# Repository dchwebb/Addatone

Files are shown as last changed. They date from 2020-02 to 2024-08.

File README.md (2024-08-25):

# Addatone
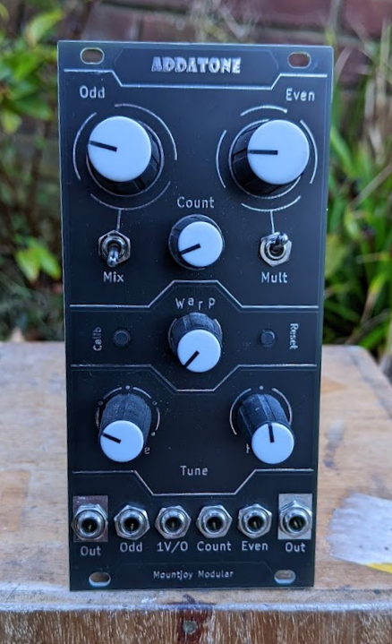
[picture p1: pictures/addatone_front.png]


Overview
--------

Addatone is a Eurorack oscillator using additive synthesis. It is a two channel oscillator with channel one outputting fundamental and odd harmonics and channel two fundamental and even harmonics.

Each channel has potentiometer and CV control over the number of harmonics with higher harmonics progressively attenuated. In addition a 'Count' pot and CV input hard-limit the total number of audible harmonics. A warp control progressively detunes the odd harmonics up and even harmonics down.

Channel one has a mix switch which allows a mix of both channels to be output from channel one. Channel two has a multiply switch which allows a multiple of both channels to be output from channel two (ie a ring modulation effect).

The final controls are an octave potentiometer covering a five octave range and a fine tune control covering around an octave.

Architecture
------------

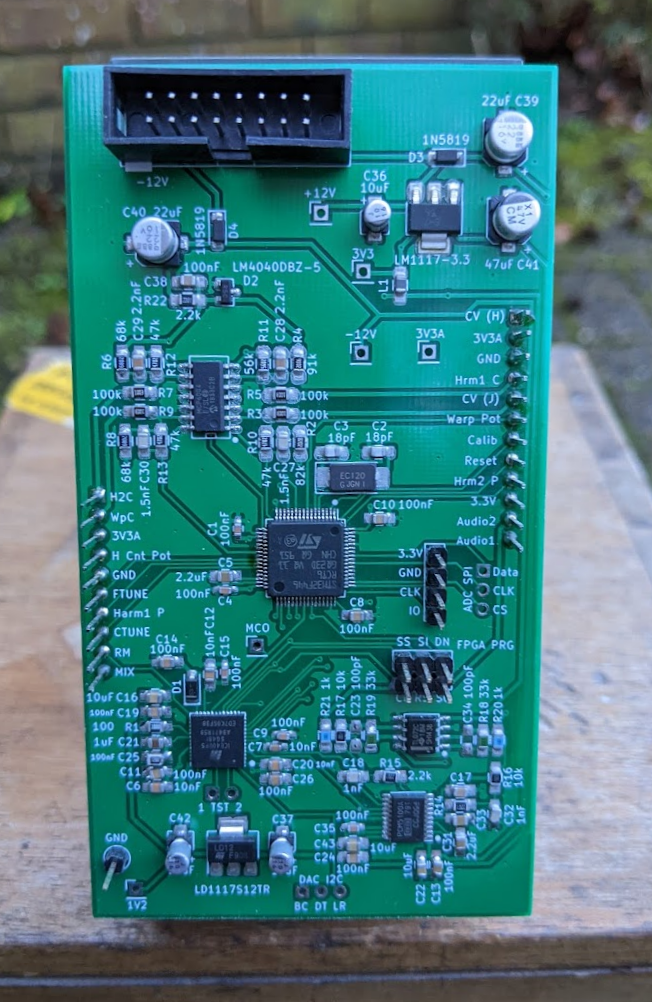
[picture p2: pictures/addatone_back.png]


The core sound generator is an ICE40UP5K FPGA from Lattice. This is responsible for generating the harmonics, mixing/multiplying and then outputting to the DAC via I2S protocol.

The module also contains an STM32F446 microcontroller which holds the FPGA bitstream in internal flash memory; this is used to program the FPGA on start-up via SPI. In addition the STM32 is used as an ADC to digitise and scale all potentiometer and CV control data. This is periodically transferred to the FPGA via SPI. The STM32 is clocked from an external 12MHz crystal. This is also used to drive the FPGA clock via the STM32 MCO (Master Clock Output) peripheral.

The DAC is a Texas Instruments PCM5100APW, operating 2 channels at 16 bits, 48kHz. Two op-amps are used to scale input CV voltages and to amplify the DAC output to Eurorack levels (8V peak to peak).

FPGA
----

A look-up table in block RAM (Sine_LUT) holds 2048 16 bit samples containing a single cycle sine wave. Individual harmonics are generated by traversing the LUT at a speed relative to the harmonic frequency.

The SamplePos_RAM 256 x 16 bit look-up table holds the current Sine LUT position of each harmonic. This position is advanced according to the harmonic's frequency at each sample and the sine sample is scaled and added to an accumulator. The initial values of the sample position LUT are pre-calculated to minimise 'crest factor'. If each harmonic started at position 0 of a sine wave then peaks and troughs would coincide to create a wave with an amplitude greater than the dynamic range of the system.

A graphical javascript tool to visualise and calculate minimal crest factor sample positions is available here:
https://htmlpreview.github.io/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

The FPGA receives its control data from the ADCs processed in the STM32. These are periodically sent via SPI and decoded using a custom peripheral (ADC_SPI_In).

The DAC_I2S module is a custom peripheral used to dispatch the final sample values to the DAC via the I2S protocol.

The 12MHz clock received from the STM32 MCO is scaled to the ICE40's maximum clock frequency of 48MHz.

The ICE40 bitstream is developed in Lattice's Radiant IDE. Full source code here: https://github.com/dchwebb/Addatone/tree/master/Addatone_ICE40

STM32 Microcontroller
---------------------

The module includes an STM32F446 MCU that carries out various helper roles. The firmware was developed in STM's CubeIDE and available here: https://github.com/dchwebb/Addatone/tree/master/Addatone_STM32F446

The FPGA bitstream is stored in the MCU's flash memory and is programmed into the FPGA at startup using an STM32 SPI peripheral (see fpgaHandler::ProgramBitstream method). Once the FPGA is programmed the ADC data derived from external CV control and potentiometers is processed, scaled and transmitted in a periodic packet to the FPGA via SPI (see fpgaHandler::SendControls method).

Calibration
-----------

The 'calib' button allows the setting of the mid point of the fine tune and the spread of the tuning. To start calibration turn the Octave and Fine Tune knobs to their mid point position.

Press the Calib button. Changing the Fine Tune knob will alter the pitch. Turning the Octave knob clockwise will decrease the tuning spread, and vice versa.

When calibration is complete press the Calib button again. Turning the Fine Tune knob to the center position should set the correct pitch.

To erase the configured calibration hold the Calib button down when powering on the module.

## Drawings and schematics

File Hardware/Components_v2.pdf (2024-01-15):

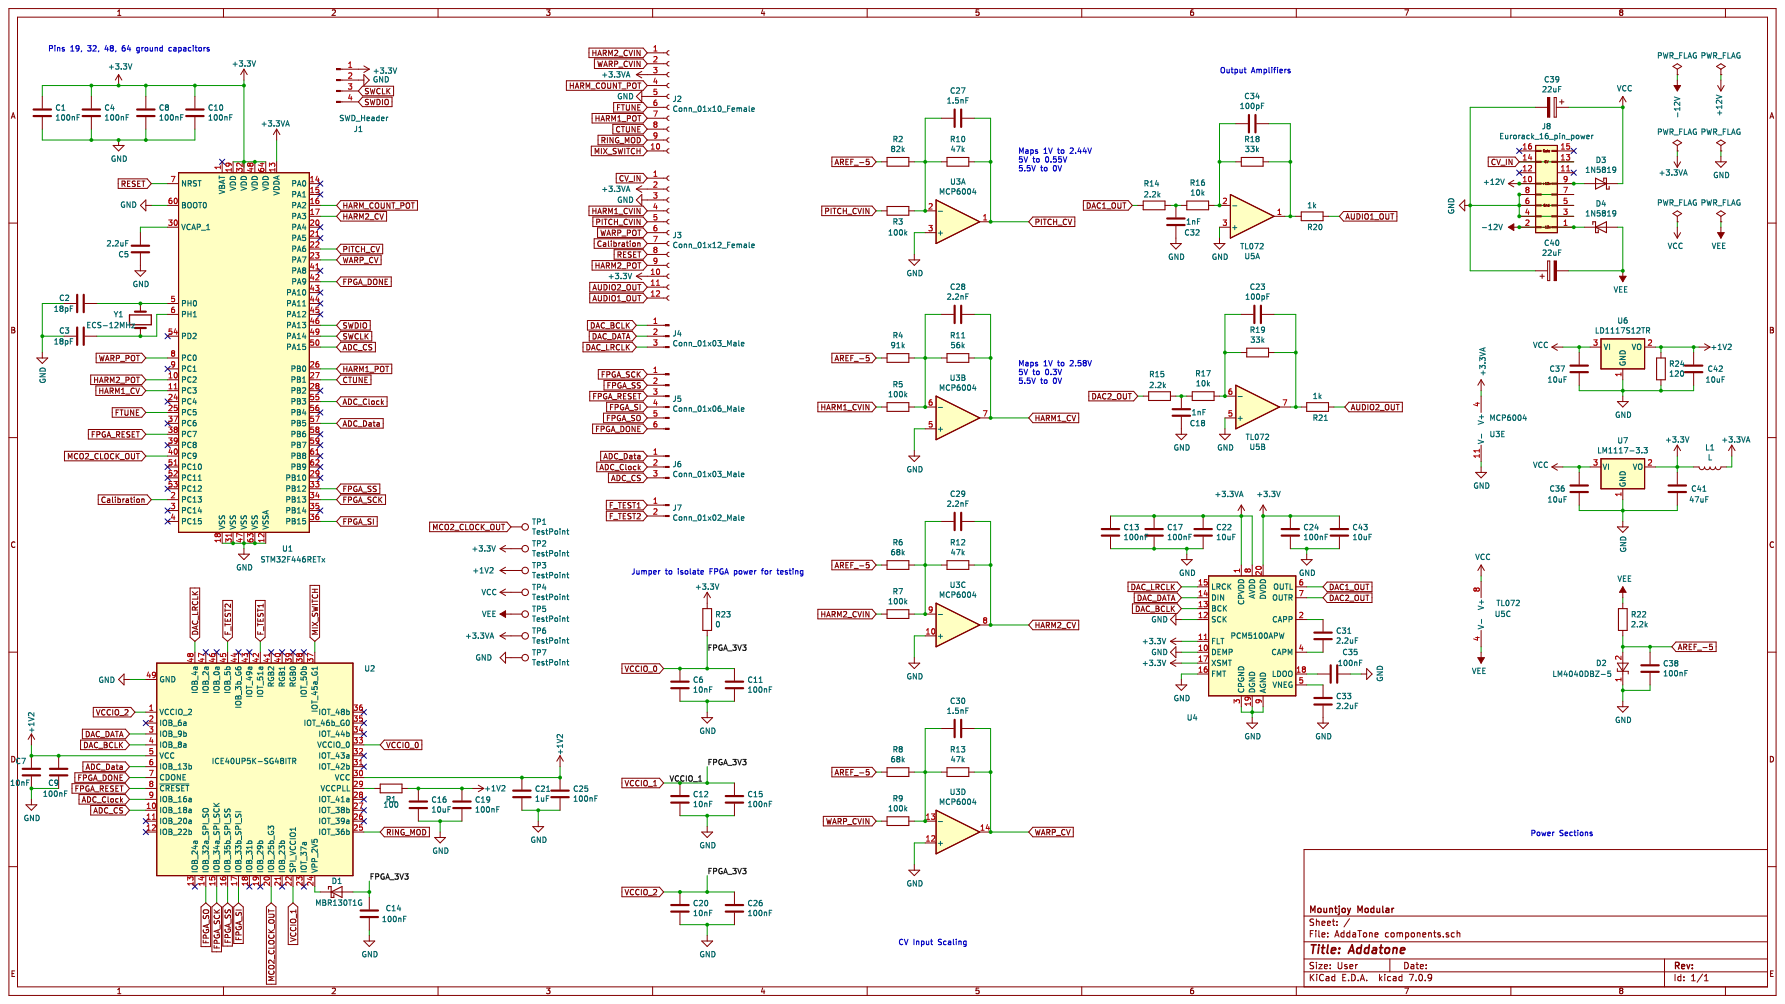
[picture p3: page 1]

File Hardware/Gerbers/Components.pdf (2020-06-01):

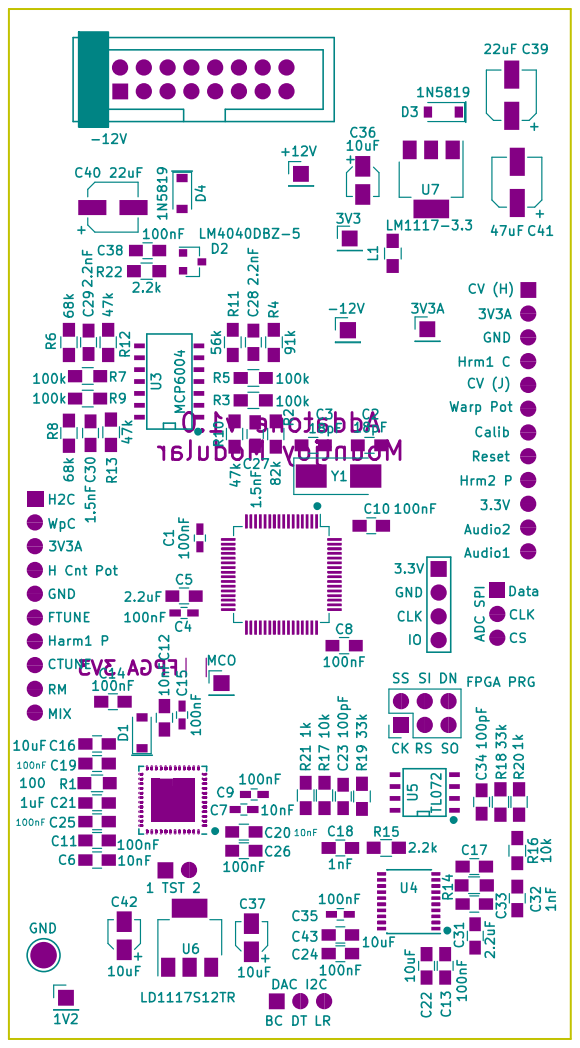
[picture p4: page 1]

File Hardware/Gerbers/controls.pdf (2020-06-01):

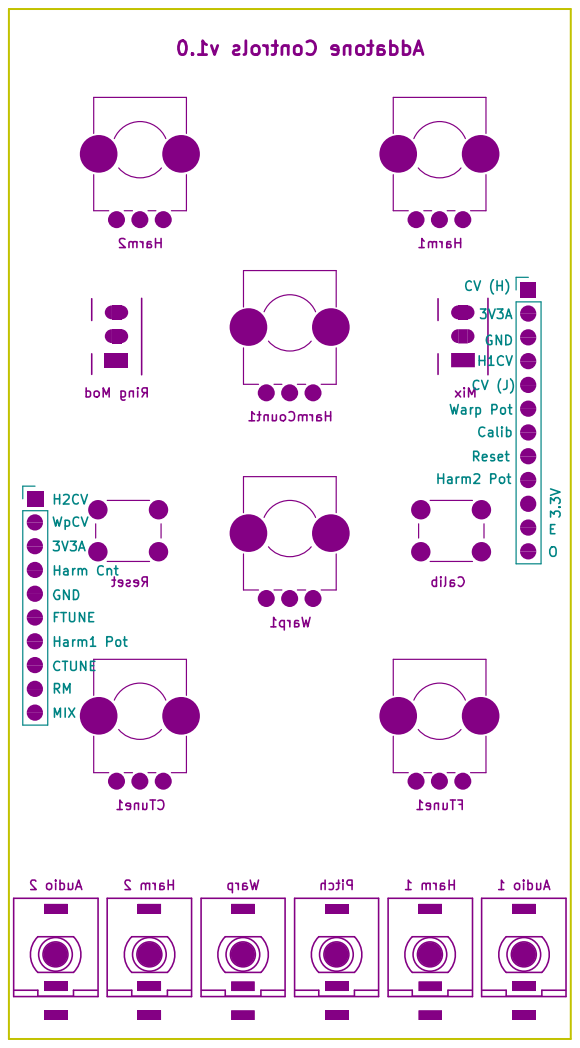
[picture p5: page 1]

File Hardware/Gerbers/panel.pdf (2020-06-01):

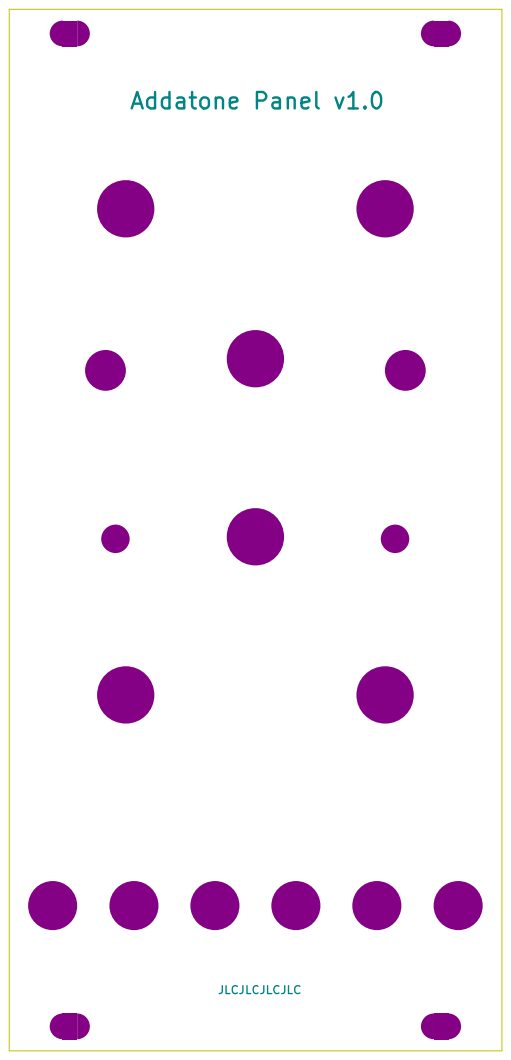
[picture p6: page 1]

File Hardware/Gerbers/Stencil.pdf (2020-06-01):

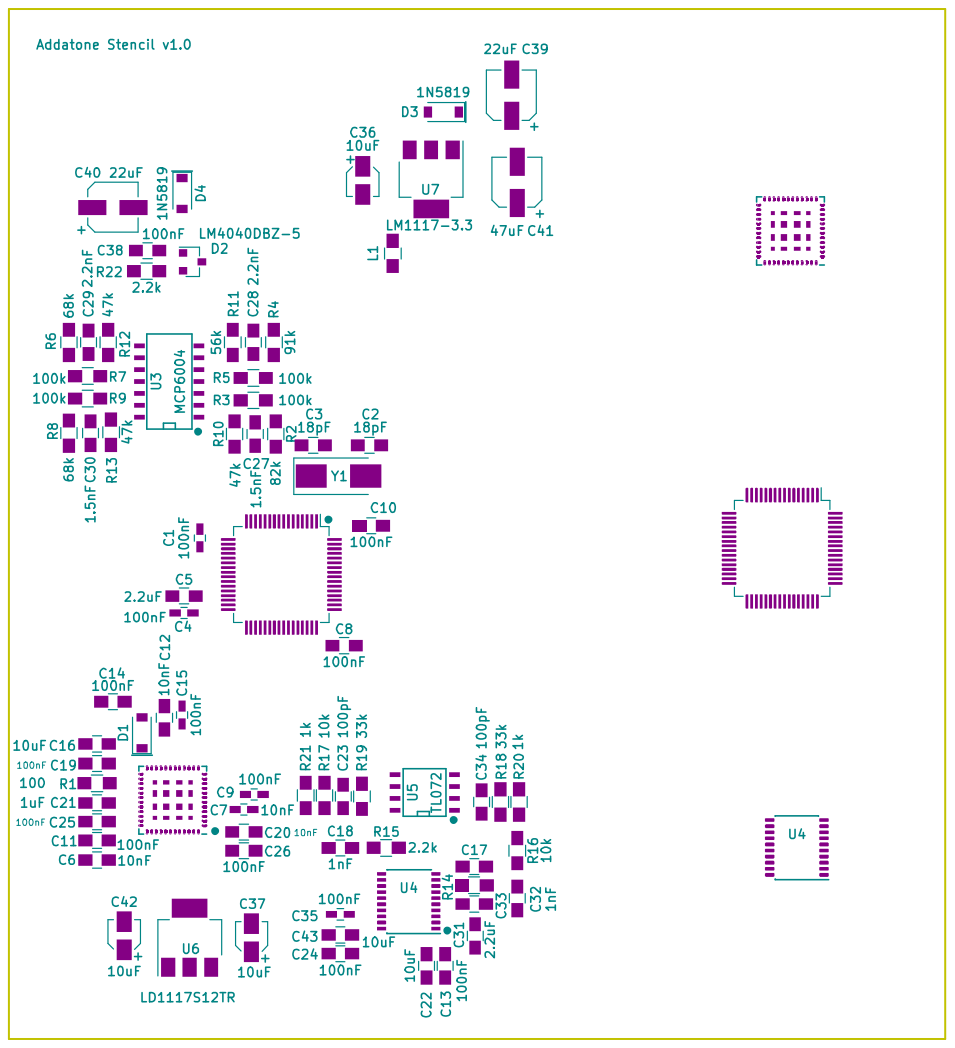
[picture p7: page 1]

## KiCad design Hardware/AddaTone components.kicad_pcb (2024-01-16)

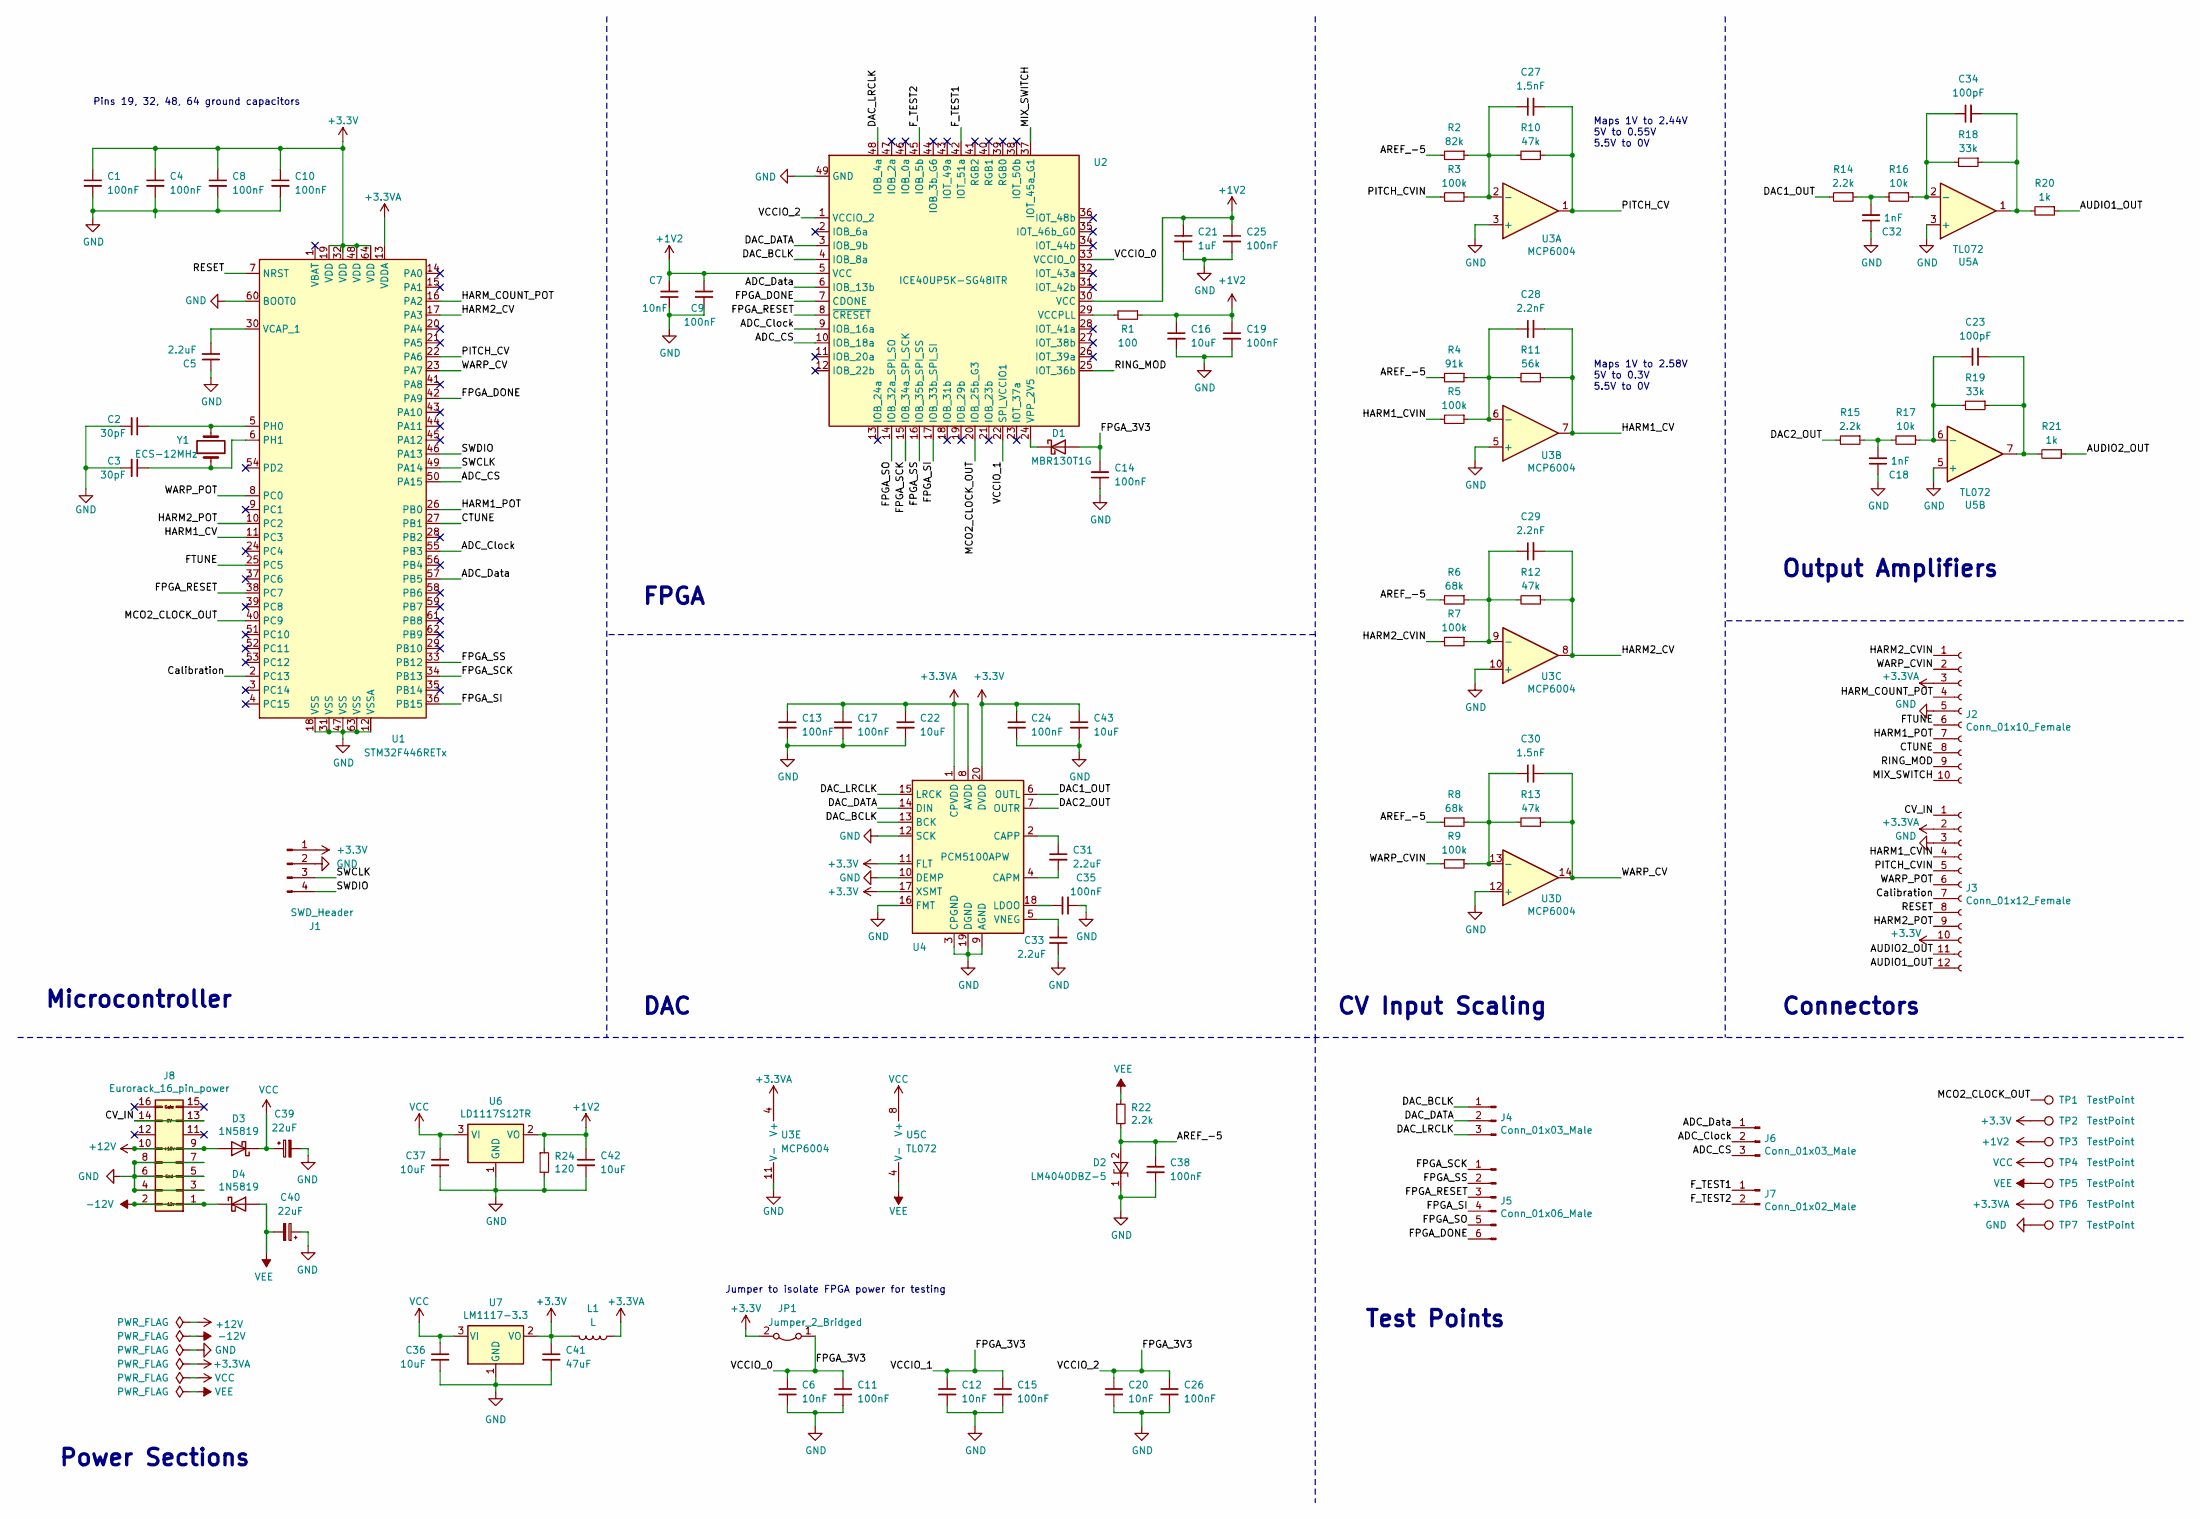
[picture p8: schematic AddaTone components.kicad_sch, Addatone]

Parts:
C1, C4, C9, C15, C35: 100nF; C_0603_1608Metric_Pad1.08x0.95mm_HandSolder
C2, C3: 30pF; C_0805_2012Metric_Pad1.18x1.45mm_HandSolder
C5, C31, C33: 2.2uF; C_0805_2012Metric_Pad1.18x1.45mm_HandSolder
C6, C7, C12, C20: 10nF; C_0805_2012Metric_Pad1.18x1.45mm_HandSolder
C8, C10, C11, C13, C14, C17, C19, C24, C25, C26, C38: 100nF; C_0805_2012Metric_Pad1.18x1.45mm_HandSolder
C16, C22, C43: 10uF; C_0805_2012Metric_Pad1.18x1.45mm_HandSolder
C18, C32: 1nF; C_0805_2012Metric_Pad1.18x1.45mm_HandSolder
C21: 1uF; C_0805_2012Metric_Pad1.18x1.45mm_HandSolder
C23, C34: 100pF; C_0805_2012Metric_Pad1.18x1.45mm_HandSolder
C27, C30: 1.5nF; C_0805_2012Metric_Pad1.18x1.45mm_HandSolder
C28, C29: 2.2nF; C_0805_2012Metric_Pad1.18x1.45mm_HandSolder
C36, C37, C42: 10uF; CP_Elec_3x5.3
C39, C40: 22uF; CP_Elec_5x5.3
C41: 47uF; CP_Elec_5x5.3
D1: MBR130T1G; D_SOD-123
D2: LM4040DBZ-5; SOT-23
D3, D4: 1N5819; D_SOD-123
J1: SWD_Header; SWD_header
J2: Conn_01x10_Female; PinSocket_1x10_P2.54mm_Vertical
J3: Conn_01x12_Female; PinSocket_1x12_P2.54mm_Vertical
J4, J6: Conn_01x03_Male; PinHeader_1x03_P2.54mm_Vertical
J5: Conn_01x06_Male; PinHeader_2x03_P2.54mm_Vertical
J7: Conn_01x02_Male; PinHeader_1x02_P2.54mm_Vertical
J8: Eurorack_16_pin_power; Eurorack_16_pin_header
JP1: Jumper_2_Bridged; SolderJumper-2_P1.3mm_Bridged_Pad1.0x1.5mm
L1: L; L_0805_2012Metric_Pad1.15x1.40mm_HandSolder
R1: 100; R_0805_2012Metric_Pad1.20x1.40mm_HandSolder
R2: 82k; R_0805_2012Metric_Pad1.20x1.40mm_HandSolder
R3, R5, R7, R9: 100k; R_0805_2012Metric_Pad1.20x1.40mm_HandSolder
R4: 91k; R_0805_2012Metric_Pad1.20x1.40mm_HandSolder
R6, R8: 68k; R_0805_2012Metric_Pad1.20x1.40mm_HandSolder
R10, R12, R13: 47k; R_0805_2012Metric_Pad1.20x1.40mm_HandSolder
R11: 56k; R_0805_2012Metric_Pad1.20x1.40mm_HandSolder
R14, R15, R22: 2.2k; R_0805_2012Metric_Pad1.20x1.40mm_HandSolder
R16, R17: 10k; R_0805_2012Metric_Pad1.20x1.40mm_HandSolder
R18, R19: 33k; R_0805_2012Metric_Pad1.20x1.40mm_HandSolder
R20, R21: 1k; R_0805_2012Metric_Pad1.20x1.40mm_HandSolder
R24: 120; R_0805_2012Metric_Pad1.20x1.40mm_HandSolder
TP1, TP2, TP3, TP4, TP5, TP6, TP7: TestPoint; TestPoint_THTPad_2.0x2.0mm_Drill1.0mm
U1: STM32F446RETx; LQFP-64_10x10mm_P0.5mm
U2: ICE40UP5K-SG48ITR; ICE40_QFN-48-1EP_7x7mm_Pitch0.5mm
U3: MCP6004; SOIC-14_3.9x8.7mm_P1.27mm
U4: PCM5100APW; SSOP-20_4.4x6.5mm_Pitch0.65mm_Round_Pads
U5: TL072; SOIC-8_3.9x4.9mm_P1.27mm
U6: LD1117S12TR; SOT-223
U7: LM1117-3.3; SOT-223
Y1: ECS-12MHz; Crystal_SMD_0603-2pin_6.0x3.5mm_HandSoldering

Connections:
+1V2: C7.1, C9.1, C16.1, C19.1, C21.1, C25.1, C42.1, R1.1, R24.1, TP3.1, U2.5 (VCC), U2.30 (VCC), U6.2 (VO)
+3.3VA: C13.1, C17.1, C22.1, J2.3, J3.2, L1.1, TP6.1, U1.13 (VDDA), U3.4 (V+), U4.1 (CPVDD), U4.8 (AVDD)
+3V3: C1.1, C4.1, C8.1, C10.1, C24.1, C41.1, C43.1, J1.1, J3.10, JP1.2 (B), L1.2, TP2.1, U1.19 (VDD), U1.32 (VDD), U1.48 (VDD), U1.64 (VDD), U4.11 (FLT), U4.17 (XSMT), U4.20 (DVDD), U7.2 (VO)
+12V: D3.2 (A), J8.9, J8.10
-12V: D4.1 (K), J8.1, J8.2
/ADC_CS: J6.3, U1.50 (PA15), U2.10 (IOB_18a)
/ADC_Clock: J6.2, U1.55 (PB3), U2.9 (IOB_16a)
/ADC_Data: J6.1, U1.57 (PB5), U2.6 (IOB_13b)
/AREF_-5: C38.1, D2.2 (A), R2.2, R4.2, R6.2, R8.2, R22.2
/AUDIO1_OUT: J3.12, R20.1
/AUDIO2_OUT: J3.11, R21.1
/CTUNE: J2.8, U1.27 (PB1)
/CV_IN: J3.1, J8.13, J8.14
/Calibration: J3.7, U1.2 (PC13)
/DAC1_OUT: R14.2, U4.6 (OUTL)
/DAC2_OUT: R15.2, U4.7 (OUTR)
/DAC_BCLK: J4.1, U2.4 (IOB_8a), U4.13 (BCK)
/DAC_DATA: J4.2, U2.3 (IOB_9b), U4.14 (DIN)
/DAC_LRCLK: J4.3, U2.48 (IOB_4a), U4.15 (LRCK)
/FPGA_3V3: C6.1, C11.1, C12.1, C14.2, C15.1, C20.1, C26.1, D1.2 (A), JP1.1 (A), U2.1 (VCCIO_2), U2.22 (SPI_VCCIO1), U2.33 (VCCIO_0)
/FPGA_DONE: J5.6, U1.42 (PA9), U2.7 (CDONE)
/FPGA_RESET: J5.3, U1.38 (PC7), U2.8 (~CRESET)
/FPGA_SCK: J5.1, U1.34 (PB13), U2.15 (IOB_34a_SPI_SCK)
/FPGA_SI: J5.4, U1.36 (PB15), U2.17 (IOB_33b_SPI_SI)
/FPGA_SO: J5.5, U2.14 (IOB_32a_SPI_SO)
/FPGA_SS: J5.2, U1.33 (PB12), U2.16 (IOB_35b_SPI_SS)
/FTUNE: J2.6, U1.25 (PC5)
/F_TEST1: J7.1, U2.42 (IOT_51a)
/F_TEST2: J7.2, U2.45 (IOB_5b)
/HARM1_CV: C28.2, R11.1, U1.11 (PC3), U3.7
/HARM1_CVIN: J3.4, R5.2
/HARM1_POT: J2.7, U1.26 (PB0)
/HARM2_CV: C29.2, R12.1, U1.17 (PA3), U3.8
/HARM2_CVIN: J2.1, R7.2
/HARM2_POT: J3.9, U1.10 (PC2)
/HARM_COUNT_POT: J2.4, U1.16 (PA2)
/MCO2_CLOCK_OUT: TP1.1, U1.40 (PC9), U2.20 (IOB_25b_G3)
/MIX_SWITCH: J2.10, U2.37 (IOT_45a_G1)
/PITCH_CV: C27.2, R10.1, U1.22 (PA6), U3.1
/PITCH_CVIN: J3.5, R3.2
/RESET: J3.8, U1.7 (NRST)
/RING_MOD: J2.9, U2.25 (IOT_36b)
/SWCLK: J1.3, U1.49 (PA14)
/SWDIO: J1.4, U1.46 (PA13)
/WARP_CV: C30.2, R13.1, U1.23 (PA7), U3.14
/WARP_CVIN: J2.2, R9.2
/WARP_POT: J3.6, U1.8 (PC0)
GND: C1.2, C2.2, C3.2, C4.2, C5.1, C6.2, C7.2, C8.2, C9.2, C10.2, C11.2, C12.2, C13.2, C14.1, C15.2, C16.2, C17.2, C18.1, C19.2, C20.2, C21.2, C22.2, C24.2, C25.2, C26.2, C32.1, C33.2, C35.1, C36.2, C37.2, C38.2, C39.2, C40.1, C41.2, C42.2, C43.2, D2.1 (K), J1.2, J2.5, J3.3, J8.3, J8.4, J8.5, J8.6, J8.7, J8.8, R24.2, TP7.1, U1.12 (VSSA), U1.18 (VSS), U1.31 (VSS), U1.47 (VSS), U1.60 (BOOT0), U1.63 (VSS), U2.49 (GND), U3.3 (+), U3.5 (+), U3.10 (+), U3.11 (V-), U3.12 (+), U4.3 (CPGND), U4.9 (AGND), U4.10 (DEMP), U4.12 (SCK), U4.16 (FMT), U4.19 (DGND), U5.3 (+), U5.5 (+), U6.1 (GND), U7.1 (GND)
unnamed: C18.2, R15.1, R17.2
unnamed: C23.2, R19.1, R21.2, U5.7
unnamed: C32.2, R14.1, R16.2
unnamed: C34.2, R18.1, R20.2, U5.1
unnamed: D1.1 (K), U2.24 (VPP_2V5)
unnamed: C2.1, U1.5 (PH0), Y1.2
unnamed: C3.1, U1.6 (PH1), Y1.1
unnamed: C5.2, U1.30 (VCAP_1)
unnamed: R1.2, U2.29 (VCCPLL)
unnamed: C27.1, R2.1, R3.1, R10.2, U3.2 (-)
unnamed: C28.1, R4.1, R5.1, R11.2, U3.6 (-)
unnamed: C29.1, R6.1, R7.1, R12.2, U3.9 (-)
unnamed: C30.1, R8.1, R9.1, R13.2, U3.13 (-)
unnamed: C31.2, U4.4 (CAPM)
unnamed: C31.1, U4.2 (CAPP)
unnamed: C35.2, U4.18 (LDOO)
unnamed: C33.1, U4.5 (VNEG)
unnamed: C34.1, R16.1, R18.2, U5.2 (-)
unnamed: C23.1, R17.1, R19.2, U5.6 (-)
VCC: C36.1, C37.1, C39.1, D3.1 (K), TP4.1, U5.8 (V+), U6.3 (VI), U7.3 (VI)
VEE: C40.2, D4.2 (A), R22.1, TP5.1, U5.4 (V-)

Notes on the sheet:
Pins 19, 32, 48, 64 ground capacitors
Test Points
Power Sections
DAC
Jumper to isolate FPGA power for testing
Output Amplifiers
Microcontroller
Maps 1V to 2.44V 5V to 0.55V 5.5V to 0V
Maps 1V to 2.58V 5V to 0.3V 5.5V to 0V
CV Input Scaling
Connectors
FPGA

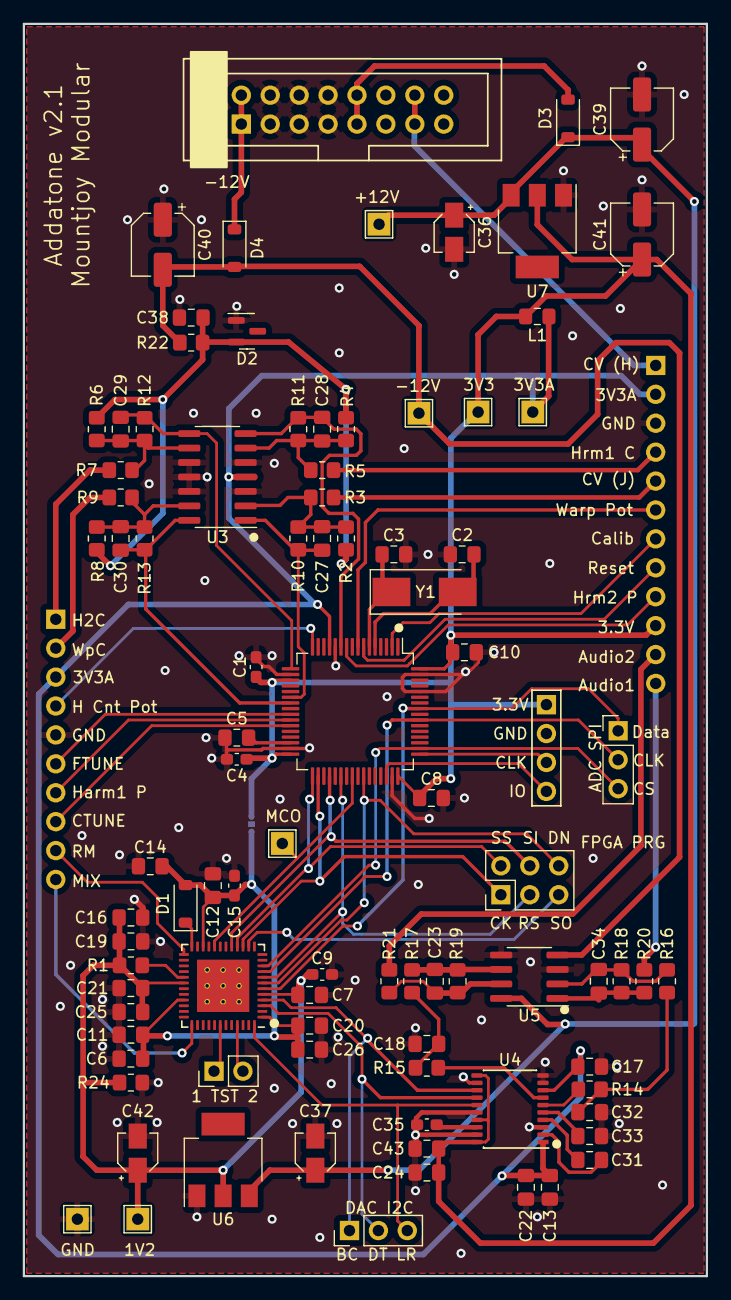
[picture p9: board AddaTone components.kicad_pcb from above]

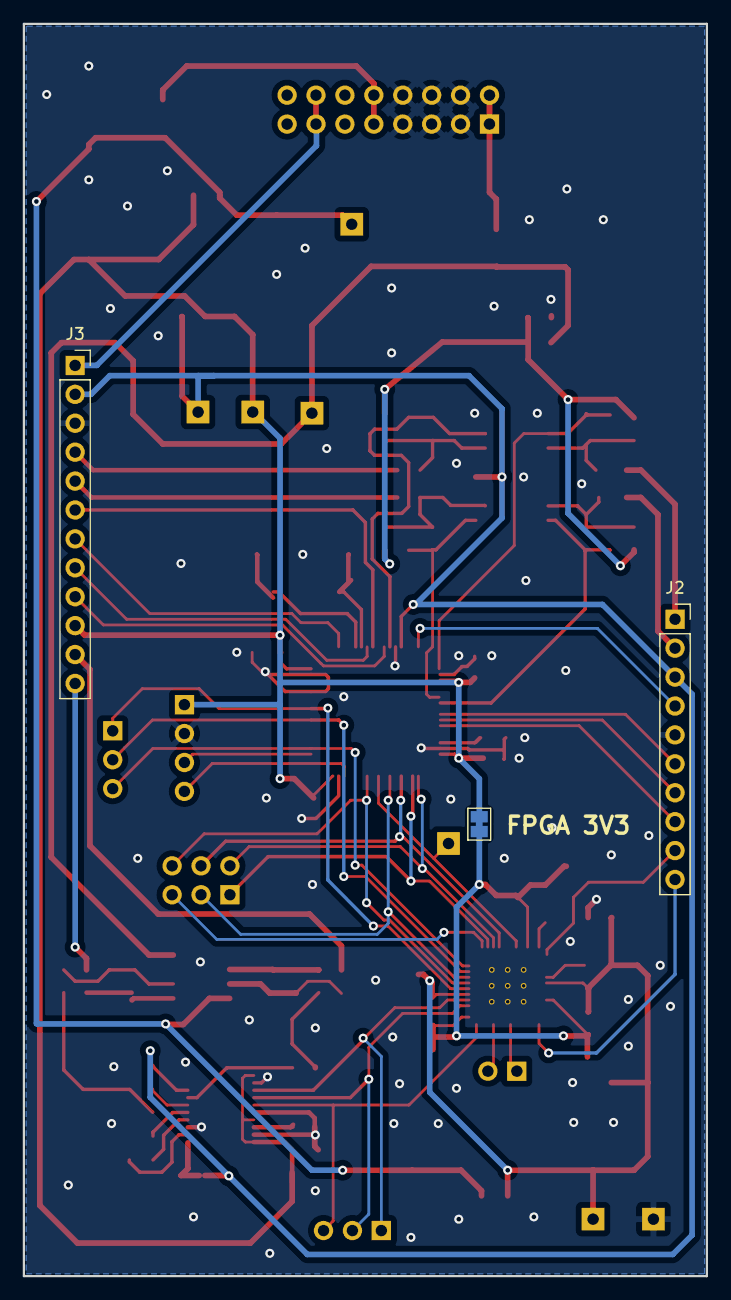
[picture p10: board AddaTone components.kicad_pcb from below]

Board: 2 copper layers, 60.0 x 110.0 mm, 95 parts (3 on the bottom side), 69 nets.

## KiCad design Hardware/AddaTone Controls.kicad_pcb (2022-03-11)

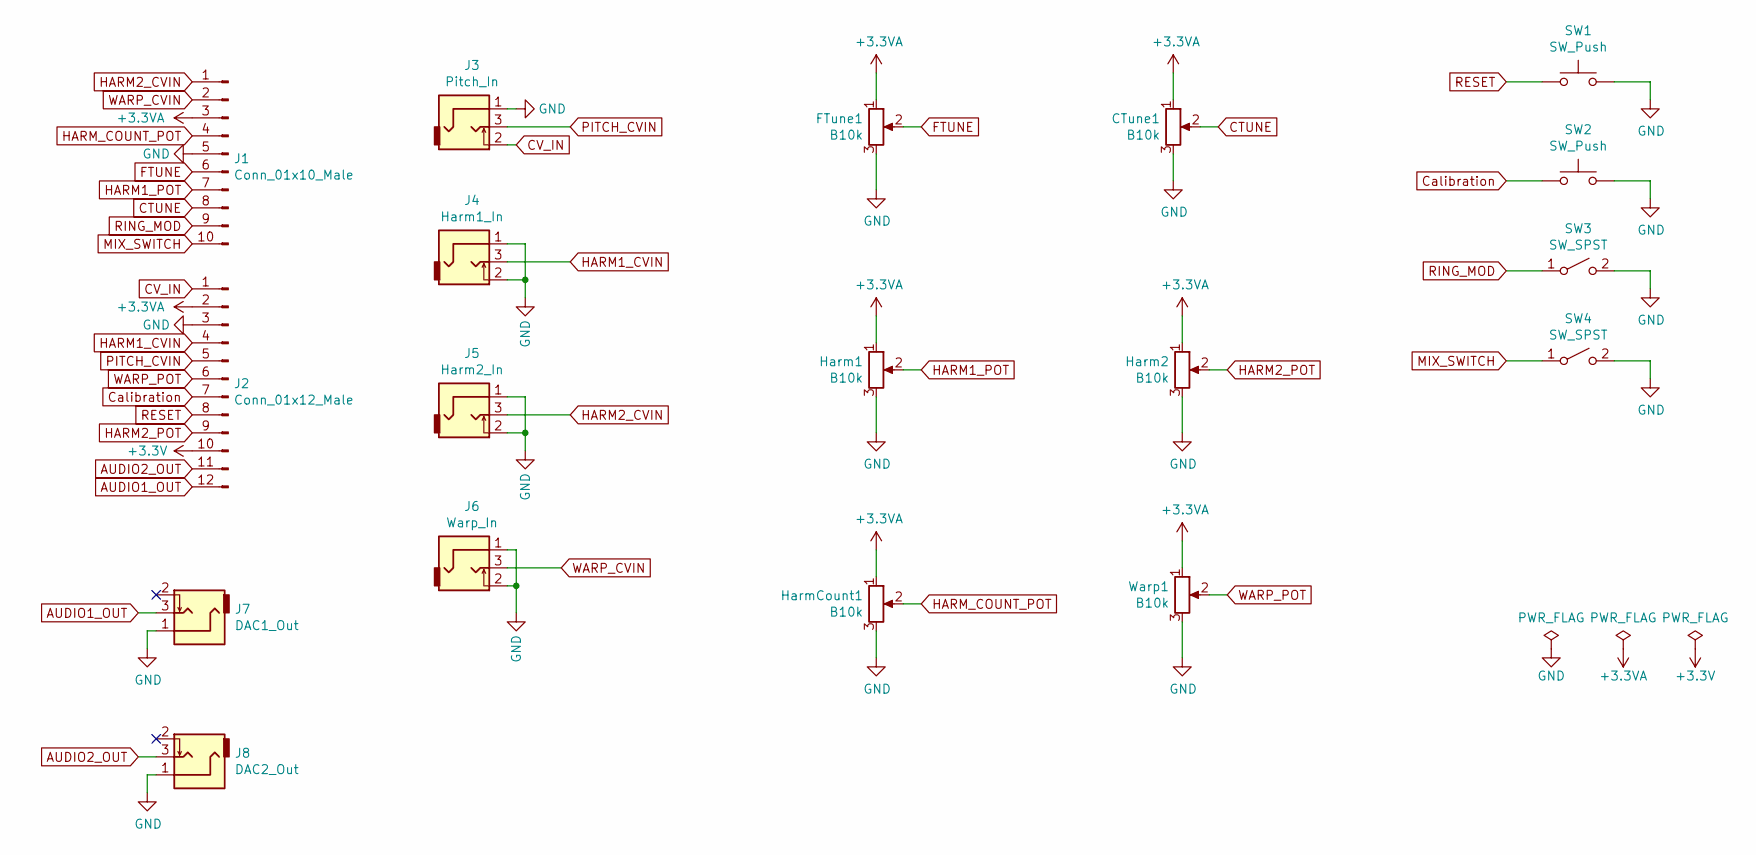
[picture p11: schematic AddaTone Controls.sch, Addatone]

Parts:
CTune1: B10k; Alpha_9mm_Potentiometer
FTune1: B10k; Alpha_9mm_Potentiometer
Harm1, Harm2: B10k; Alpha_9mm_Potentiometer
HarmCount1: B10k; Alpha_9mm_Potentiometer
J1: Conn_01x10_Male; Pin_Header_Straight_1x10_Pitch2.54mm
J2: Conn_01x12_Male; Pin_Header_Straight_1x12_Pitch2.54mm
J3: Pitch_In; THONKICONN_hole
J4: Harm1_In; THONKICONN_hole
J5: Harm2_In; THONKICONN_hole
J6: Warp_In; THONKICONN_hole
J7: DAC1_Out; THONKICONN_hole
J8: DAC2_Out; THONKICONN_hole
SW1, SW2: SW_Push; SW_PUSH_6mm
SW3, SW4: SW_SPST; SPDTSubMiniature
Warp1: B10k; Alpha_9mm_Potentiometer

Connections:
+3.3VA: CTune1.1, FTune1.1, Harm1.1, Harm2.1, HarmCount1.1, J1.3, J2.2, Warp1.1
+3V3: J2.10
AUDIO1_OUT: J2.12, J7.3
AUDIO2_OUT: J2.11, J8.3
CTUNE: CTune1.2, J1.8
CV_IN: J2.1, J3.2
Calibration: J2.7, SW2.1
FTUNE: FTune1.2, J1.6
GND: CTune1.3, FTune1.3, Harm1.3, Harm2.3, HarmCount1.3, J1.5, J2.3, J3.1, J4.1, J4.2, J5.1, J5.2, J6.1, J6.2, J7.1, J8.1, SW1.2, SW2.2, SW3.2 (B), SW4.2 (B), Warp1.3
HARM1_CVIN: J2.4, J4.3
HARM1_POT: Harm1.2, J1.7
HARM2_CVIN: J1.1, J5.3
HARM2_POT: Harm2.2, J2.9
HARM_COUNT_POT: HarmCount1.2, J1.4
MIX_SWITCH: J1.10, SW4.1 (A)
PITCH_CVIN: J2.5, J3.3
RESET: J2.8, SW1.1
RING_MOD: J1.9, SW3.1 (A)
WARP_CVIN: J1.2, J6.3
WARP_POT: J2.6, Warp1.2

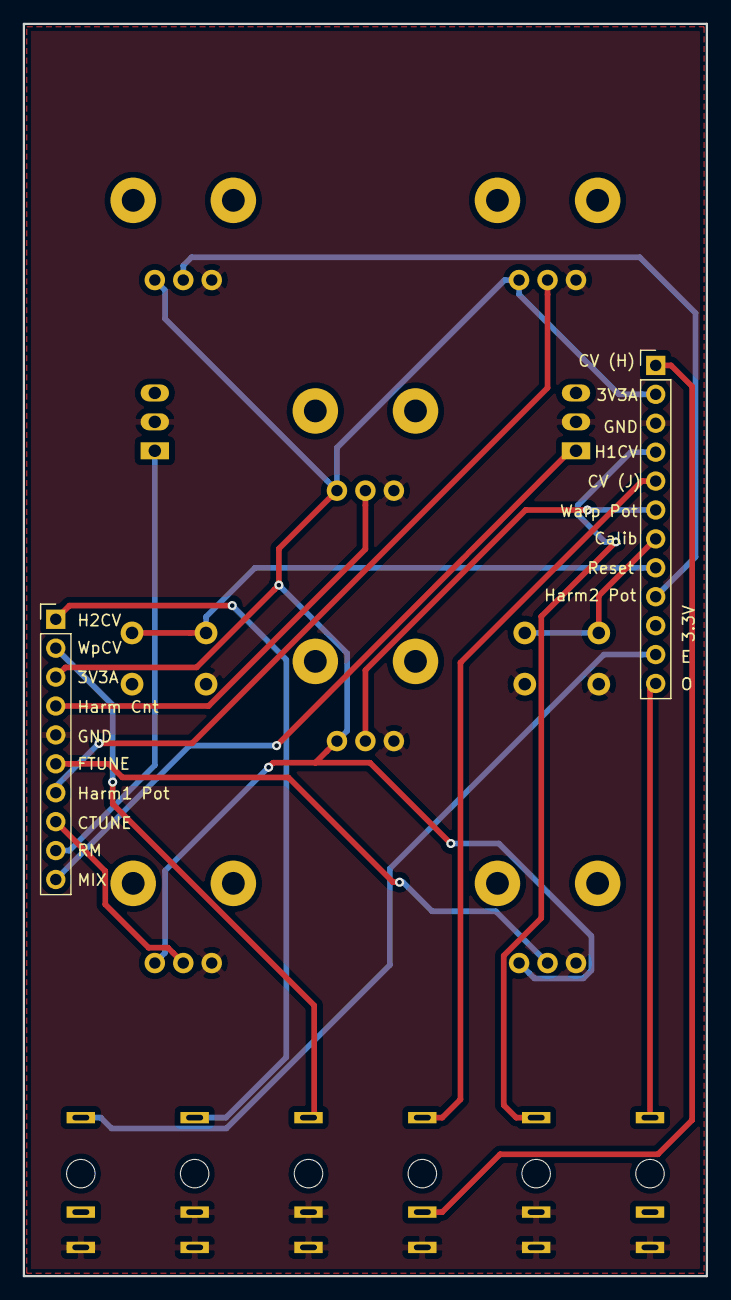
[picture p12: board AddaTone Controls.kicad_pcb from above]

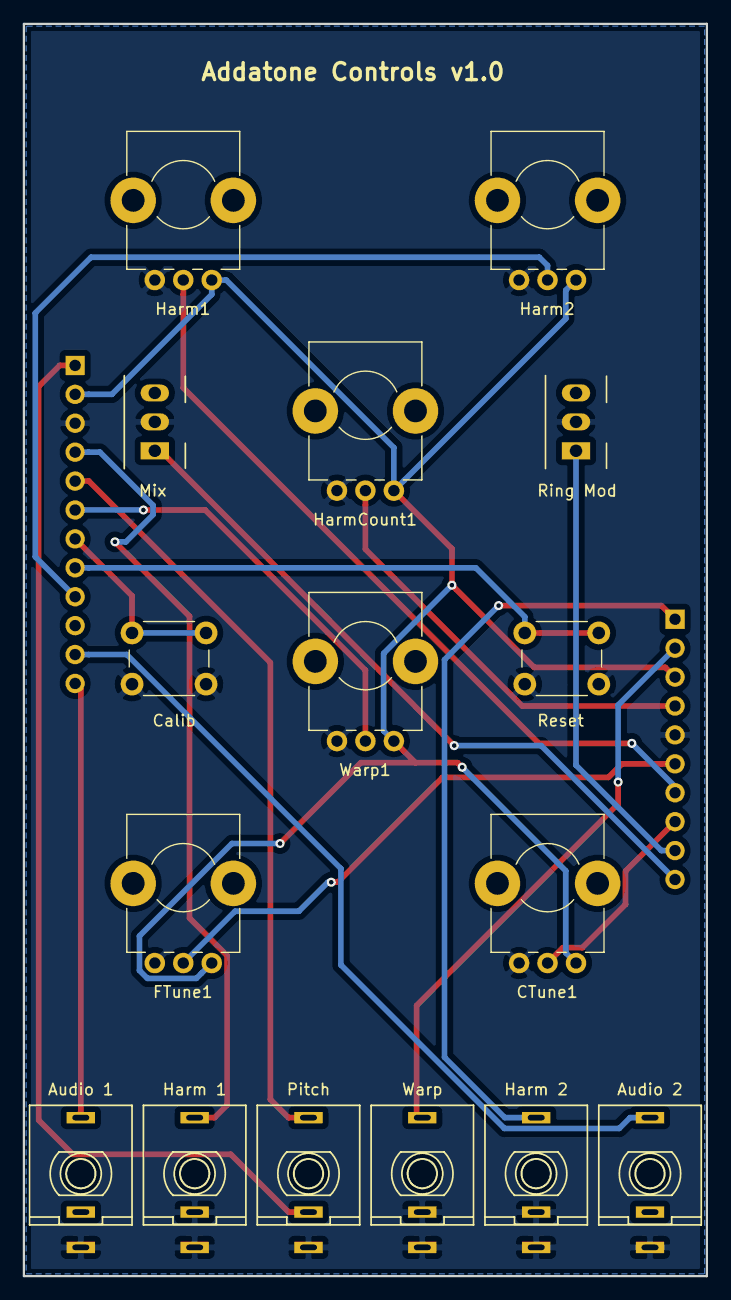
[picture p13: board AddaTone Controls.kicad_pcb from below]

Board: 2 copper layers, 60.0 x 110.0 mm, 18 parts (16 on the bottom side), 19 nets.

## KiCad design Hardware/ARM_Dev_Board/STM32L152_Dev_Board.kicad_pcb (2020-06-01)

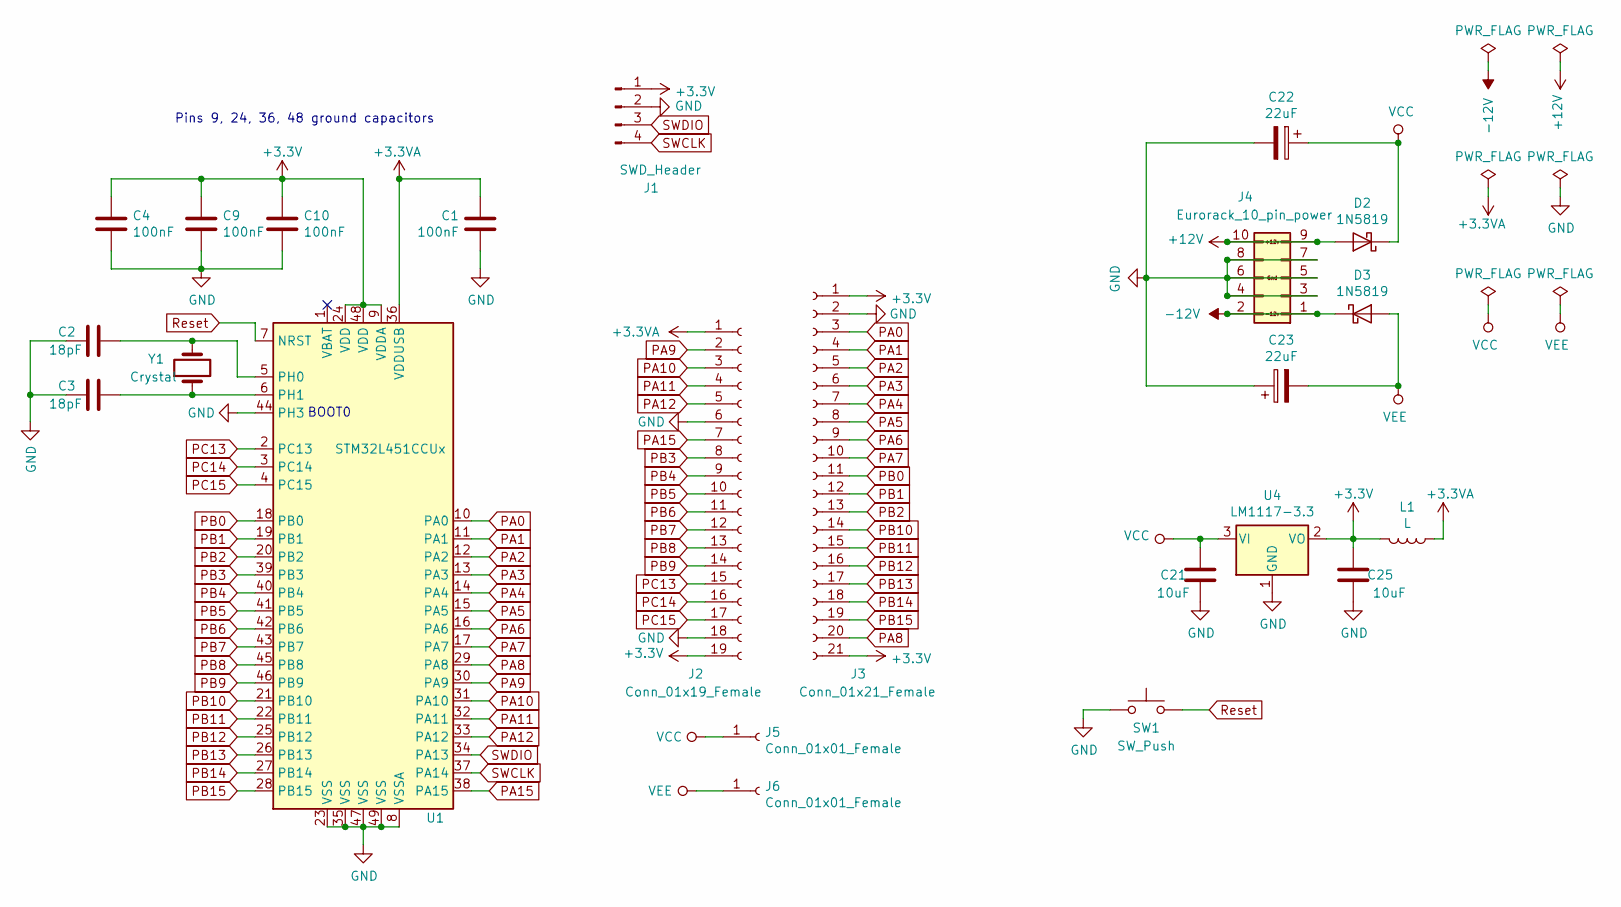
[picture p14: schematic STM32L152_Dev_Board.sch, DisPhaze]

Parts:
C1, C4, C9, C10: 100nF; C_0805_HandSoldering
C2, C3: 18pF; C_0805_HandSoldering
C21, C25: 10uF; CP_Elec_3x5.3
C22, C23: 22uF; CP_Elec_4x5.8_Big_pad
D2, D3: 1N5819; D_SOD-123
J1: SWD_Header; SWD_header
J2: Conn_01x19_Female; Pin_Header_Straight_1x19_Pitch2.54mm
J3: Conn_01x21_Female; Pin_Header_Straight_1x21_Pitch2.54mm
J4: Eurorack_10_pin_power; Pin_Header_Straight_2x05_Pitch2.54mm
J5, J6: Conn_01x01_Female; Pin_Header_Straight_1x01_Pitch2.54mm
L1: L; R_0805_HandSoldering
SW1: SW_Push; SW_SPST_EVPBF
U1: STM32L451CCUx; ICE40_QFN-48-1EP_7x7mm_Pitch0.5mm
U4: LM1117-3.3; SOT-223
Y1: Crystal; Crystal_SMD_0603-2pin_6.0x3.5mm_HandSoldering

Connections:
+3.3VA: C1.1, J2.1, L1.1, U1.36 (VDDUSB)
+3V3: C4.1, C9.1, C10.1, C25.1, J1.1, J2.19, J3.1, J3.21, L1.2, U1.9 (VDDA), U1.24 (VDD), U1.48 (VDD), U4.2 (VO)
+12V: D2.2 (A), J4.9, J4.10
-12V: D3.1 (K), J4.1, J4.2
GND: C1.2, C2.2, C3.2, C4.2, C9.2, C10.2, C21.2, C22.2, C23.1, C25.2, J1.2, J2.6, J2.18, J3.2, J4.3, J4.4, J4.5, J4.6, J4.7, J4.8, SW1.1, U1.8 (VSSA), U1.23 (VSS), U1.35 (VSS), U1.44 (PH3), U1.47 (VSS), U1.49 (VSS), U4.1 (GND)
unnamed: C2.1, U1.5 (PH0), Y1.2
unnamed: C3.1, U1.6 (PH1), Y1.1
PA0: J3.3, U1.10 (PA0)
PA1: J3.4, U1.11 (PA1)
PA2: J3.5, U1.12 (PA2)
PA3: J3.6, U1.13 (PA3)
PA4: J3.7, U1.14 (PA4)
PA5: J3.8, U1.15 (PA5)
PA6: J3.9, U1.16 (PA6)
PA7: J3.10, U1.17 (PA7)
PA8: J3.20, U1.29 (PA8)
PA9: J2.2, U1.30 (PA9)
PA10: J2.3, U1.31 (PA10)
PA11: J2.4, U1.32 (PA11)
PA12: J2.5, U1.33 (PA12)
PA15: J2.7, U1.38 (PA15)
PB0: J3.11, U1.18 (PB0)
PB1: J3.12, U1.19 (PB1)
PB2: J3.13, U1.20 (PB2)
PB3: J2.8, U1.39 (PB3)
PB4: J2.9, U1.40 (PB4)
PB5: J2.10, U1.41 (PB5)
PB6: J2.11, U1.42 (PB6)
PB7: J2.12, U1.43 (PB7)
PB8: J2.13, U1.45 (PB8)
PB9: J2.14, U1.46 (PB9)
PB10: J3.14, U1.21 (PB10)
PB11: J3.15, U1.22 (PB11)
PB12: J3.16, U1.25 (PB12)
PB13: J3.17, U1.26 (PB13)
PB14: J3.18, U1.27 (PB14)
PB15: J3.19, U1.28 (PB15)
PC13: J2.15, U1.2 (PC13)
PC14: J2.16, U1.3 (PC14)
PC15: J2.17, U1.4 (PC15)
Reset: SW1.2, U1.7 (NRST)
SWCLK: J1.4, U1.37 (PA14)
SWDIO: J1.3, U1.34 (PA13)
VCC: C21.1, C22.1, D2.1 (K), J5.1, U4.3 (VI)
VEE: C23.2, D3.2 (A), J6.1

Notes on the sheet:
Pins 9, 24, 36, 48 ground capacitors
BOOT0

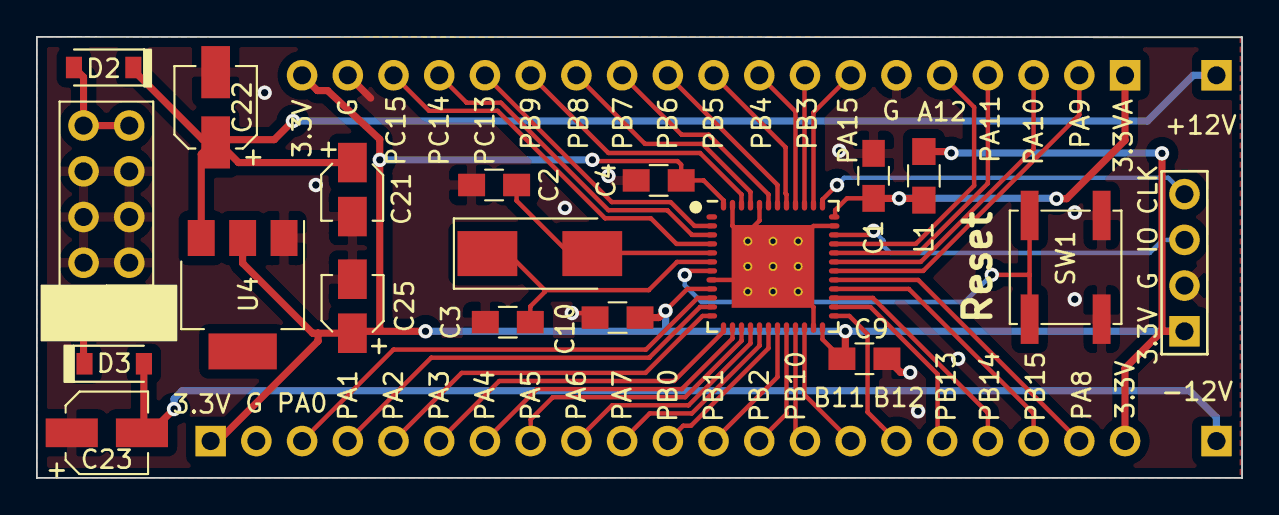
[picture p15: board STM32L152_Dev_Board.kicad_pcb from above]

Board: 2 copper layers, 67.0 x 24.5 mm, 23 parts (0 on the bottom side), 45 nets.

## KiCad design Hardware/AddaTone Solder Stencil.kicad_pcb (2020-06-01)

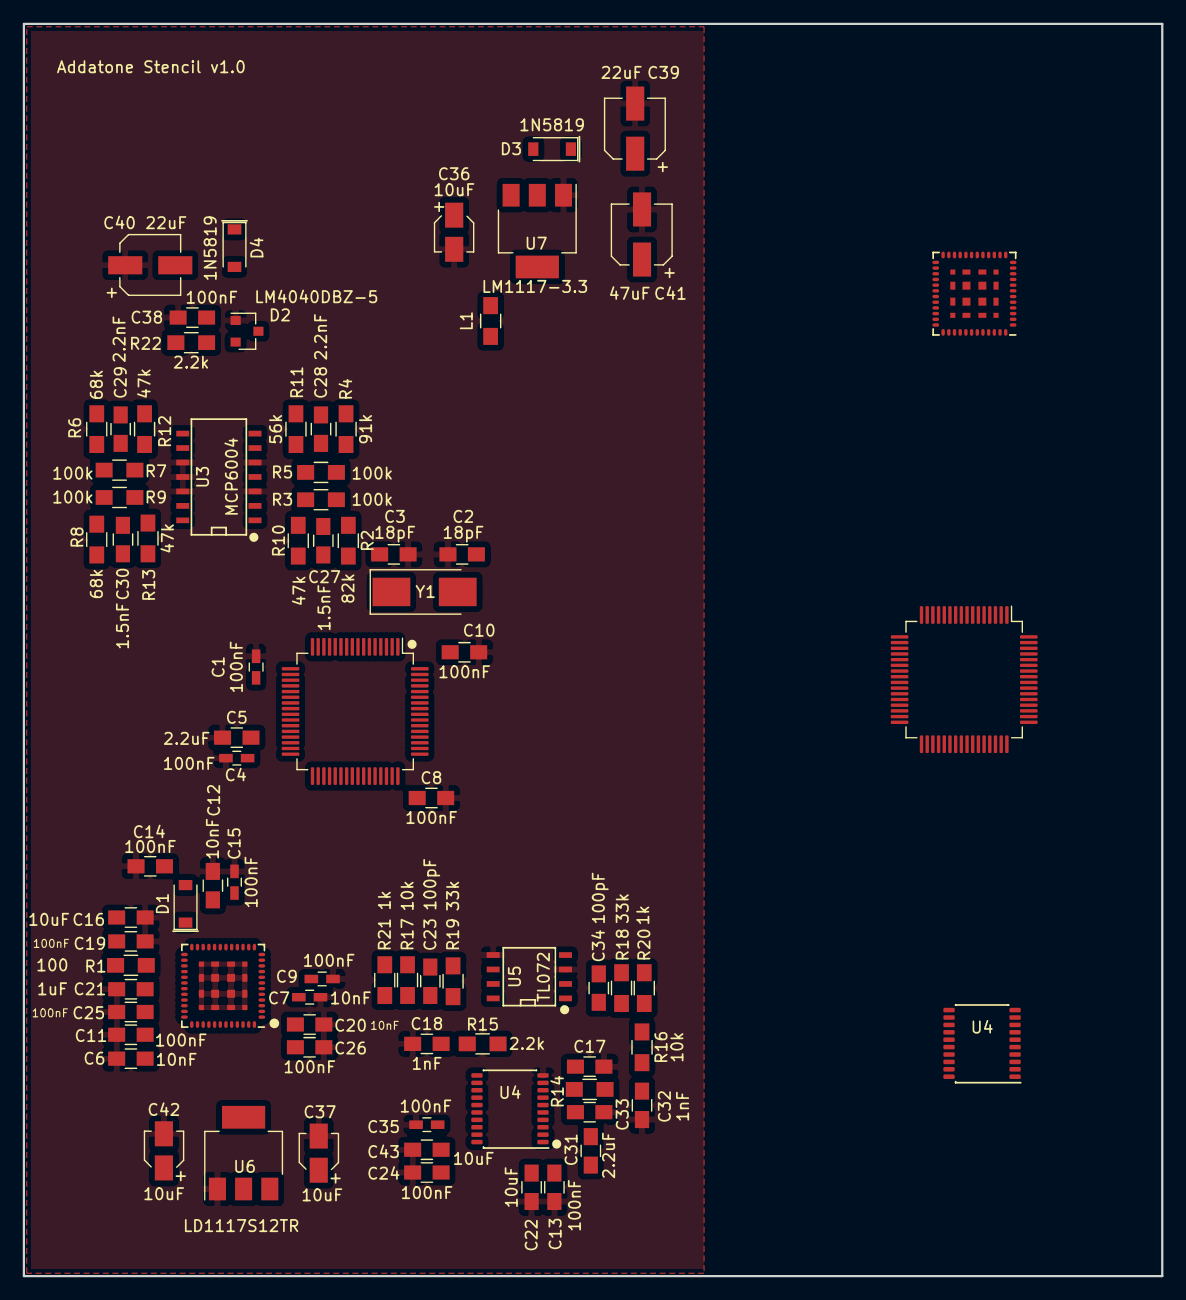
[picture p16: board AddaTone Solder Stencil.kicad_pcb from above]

Board: 2 copper layers, 100.0 x 110.0 mm, 81 parts (0 on the bottom side), 110 nets, no tracks yet.

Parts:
C1, C4, C9, C15, C35: 100nF; C_0603_HandSoldering
C2, C3: 18pF; C_0805_HandSoldering
C5, C31, C33: 2.2uF; C_0805_HandSoldering
C6, C12, C20: 10nF; C_0805_HandSoldering
C7: 10nF; C_0603_HandSoldering
C8, C10, C11, C13, C14, C17, C19, C24, C25, C26, C38: 100nF; C_0805_HandSoldering
C16, C22, C43: 10uF; C_0805_HandSoldering
C18, C32: 1nF; C_0805_HandSoldering
C21: 1uF; C_0805_HandSoldering
C23, C34: 100pF; C_0805_HandSoldering
C27, C30: 1.5nF; C_0805_HandSoldering
C28, C29: 2.2nF; C_0805_HandSoldering
C36, C37, C42: 10uF; CP_Elec_3x5.3
C39, C40: 22uF; CP_Elec_5x5.3
C41: 47uF; CP_Elec_5x5.3
D1: MBR130T1G; D_SOD-123
D2: LM4040DBZ-5; SOT-23
D3, D4: 1N5819; D_SOD-123
L1: L; L_0805_HandSoldering
R1: 100; R_0805_HandSoldering
R2: 82k; R_0805_HandSoldering
R3, R5, R7, R9: 100k; R_0805_HandSoldering
R4: 91k; R_0805_HandSoldering
R6, R8: 68k; R_0805_HandSoldering
R10, R12, R13: 47k; R_0805_HandSoldering
R11: 56k; R_0805_HandSoldering
R14, R15, R22: 2.2k; R_0805_HandSoldering
R16, R17: 10k; R_0805_HandSoldering
R18, R19: 33k; R_0805_HandSoldering
R20, R21: 1k; R_0805_HandSoldering
U1, U1#2: STM32F446RETx; LQFP-64_10x10mm_P0.5mm
U2, U2#2: ICE40UP5K-SG48ITR; ICE40_QFN-48-stencil
U3: MCP6004; SOIC-14_N
U4, U4#2: PCM5100APW; SSOP-20_4.4x6.5mm_Pitch0.65mm_Round_Pads
U5: TL072; SOIC-8-N
U6: LD1117S12TR; SOT-223
U7: LM1117-3.3; SOT-223
Y1: ECS-12MHz; Crystal_SMD_0603-2pin_6.0x3.5mm_HandSoldering

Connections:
+1V2: C7.1, C9.1, C16.1, C19.1, C21.1, C25.1, C42.1, R1.1, U2.5, U2.30, U2#2.5, U2#2.30, U6.2
+3.3VA: C13.1, C17.1, C22.1, L1.1, U1.13, U1#2.13, U3.4, U4.1, U4.8, U4#2.1, U4#2.8
ADC_CS: U1.50, U1#2.50, U2.10, U2#2.10
ADC_Clock: U1.55, U1#2.55, U2.9, U2#2.9
ADC_Data: U1.57, U1#2.57, U2.6, U2#2.6
AREF_-5: C38.1, D2.2, R2.2, R4.2, R6.2, R8.2, R22.2
CTUNE: U1.27, U1#2.27
Calibration: U1.2, U1#2.2
DAC1_OUT: R14.2, U4.6, U4#2.6
DAC2_OUT: R15.2, U4.7, U4#2.7
DAC_BCLK: U2.4, U2#2.4, U4.13, U4#2.13
DAC_DATA: U2.3, U2#2.3, U4.14, U4#2.14
DAC_LRCLK: U2.48, U2#2.48, U4.15, U4#2.15
FPGA_DONE: U1.42, U1#2.42, U2.7, U2#2.7
FPGA_RESET: U1.38, U1#2.38, U2.8, U2#2.8
FPGA_SCK: U1.34, U1#2.34, U2.15, U2#2.15
FPGA_SI: U1.36, U1#2.36, U2.17, U2#2.17
FPGA_SO: U2.14, U2#2.14
FPGA_SS: U1.33, U1#2.33, U2.16, U2#2.16
FTUNE: U1.25, U1#2.25
F_TEST1: U2.42, U2#2.42
F_TEST2: U2.45, U2#2.45
GND: C1.2, C2.2, C3.2, C4.2, C5.1, C6.2, C7.2, C8.2, C9.2, C10.2, C11.2, C12.2, C13.2, C14.1, C15.2, C16.2, C17.2, C18.1, C19.2, C20.2, C21.2, C22.2, C24.2, C25.2, C26.2, C32.1, C33.2, C35.1, C36.2, C37.2, C38.2, C39.2, C40.1, C41.2, C42.2, C43.2, D2.1, U1.12, U1.18, U1.31, U1.47, U1.60, U1.63, U1#2.12, U1#2.18, U1#2.31, U1#2.47, U1#2.60, U1#2.63, U2.49, U2#2.49, U3.3, U3.5, U3.10, U3.11, U3.12, U4.3, U4.9, U4.10, U4.12, U4.16, U4.19, U4#2.3, U4#2.9, U4#2.10, U4#2.12, U4#2.16, U4#2.19, U5.3, U5.5, U6.1, U7.1
HARM1_CV: C28.2, R11.1, U1.11, U1#2.11, U3.7
HARM1_POT: U1.26, U1#2.26
HARM2_CV: C29.2, R12.1, U1.17, U1#2.17, U3.8
HARM2_POT: U1.10, U1#2.10
HARM_COUNT_POT: U1.16, U1#2.16
MCO2_CLOCK_OUT: U1.40, U1#2.40, U2.20, U2#2.20
MIX_SWITCH: U2.37, U2#2.37
unnamed: C2.1, U1.5, U1#2.5, Y1.2
unnamed: C3.1, U1.6, U1#2.6, Y1.1
unnamed: C5.2, U1.30, U1#2.30
unnamed: C18.2, R15.1, R17.2
unnamed: C23.1, R17.1, R19.2, U5.6
unnamed: C23.2, R19.1, R21.2, U5.7
unnamed: C27.1, R2.1, R3.1, R10.2, U3.2
unnamed: C28.1, R4.1, R5.1, R11.2, U3.6
unnamed: C29.1, R6.1, R7.1, R12.2, U3.9
unnamed: C30.1, R8.1, R9.1, R13.2, U3.13
unnamed: C31.1, U4.2, U4#2.2
unnamed: C31.2, U4.4, U4#2.4
unnamed: C32.2, R14.1, R16.2
unnamed: C33.1, U4.5, U4#2.5
unnamed: C34.1, R16.1, R18.2, U5.2
unnamed: C34.2, R18.1, R20.2, U5.1
unnamed: C35.2, U4.18, U4#2.18
unnamed: D1.1, U2.24, U2#2.24
unnamed: R1.2, U2.29, U2#2.29
unnamed: U1.1, U1#2.1
unnamed: U1.3, U1#2.3
unnamed: U1.4, U1#2.4
unnamed: U1.9, U1#2.9
unnamed: U1.14, U1#2.14
unnamed: U1.15, U1#2.15
unnamed: U1.20, U1#2.20
unnamed: U1.21, U1#2.21
unnamed: U1.24, U1#2.24
unnamed: U1.28, U1#2.28
unnamed: U1.29, U1#2.29
unnamed: U1.35, U1#2.35
unnamed: U1.37, U1#2.37
unnamed: U1.39, U1#2.39
unnamed: U1.41, U1#2.41
unnamed: U1.43, U1#2.43
unnamed: U1.44, U1#2.44
unnamed: U1.45, U1#2.45
unnamed: U1.51, U1#2.51
unnamed: U1.52, U1#2.52
unnamed: U1.53, U1#2.53
unnamed: U1.54, U1#2.54
unnamed: U1.56, U1#2.56
unnamed: U1.58, U1#2.58
unnamed: U1.59, U1#2.59
unnamed: U1.61, U1#2.61
unnamed: U1.62, U1#2.62
unnamed: U2.2, U2#2.2
unnamed: U2.11, U2#2.11
unnamed: U2.12, U2#2.12
unnamed: U2.13, U2#2.13
unnamed: U2.18, U2#2.18
unnamed: U2.19, U2#2.19
unnamed: U2.21, U2#2.21
unnamed: U2.23, U2#2.23
unnamed: U2.26, U2#2.26
unnamed: U2.27, U2#2.27
unnamed: U2.28, U2#2.28
unnamed: U2.31, U2#2.31
unnamed: U2.32, U2#2.32
unnamed: U2.34, U2#2.34
unnamed: U2.35, U2#2.35
unnamed: U2.36, U2#2.36
unnamed: U2.38, U2#2.38
unnamed: U2.39, U2#2.39
unnamed: U2.40, U2#2.40
unnamed: U2.41, U2#2.41
unnamed: U2.43, U2#2.43
unnamed: U2.44, U2#2.44
unnamed: U2.46, U2#2.46
unnamed: U2.47, U2#2.47
PITCH_CV: C27.2, R10.1, U1.22, U1#2.22, U3.1
RESET: U1.7, U1#2.7
RING_MOD: U2.25, U2#2.25
SWCLK: U1.49, U1#2.49
SWDIO: U1.46, U1#2.46
VCC: C36.1, C37.1, C39.1, D3.1, U5.8, U6.3, U7.3
VCCIO_0: C1.1, C4.1, C6.1, C8.1, C10.1, C11.1, C12.1, C14.2, C15.1, C20.1, C24.1, C26.1, C41.1, C43.1, D1.2, L1.2, U1.19, U1.32, U1.48, U1.64, U1#2.19, U1#2.32, U1#2.48, U1#2.64, U2.1, U2.22, U2.33, U2#2.1, U2#2.22, U2#2.33, U4.11, U4.17, U4.20, U4#2.11, U4#2.17, U4#2.20, U7.2
VEE: C40.2, D4.2, R22.1, U5.4
WARP_CV: C30.2, R13.1, U1.23, U1#2.23, U3.14
WARP_POT: U1.8, U1#2.8

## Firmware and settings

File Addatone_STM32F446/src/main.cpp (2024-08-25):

#include "initialisation.h"
#include "fpgaHandler.h"

volatile uint32_t SysTickVal;

extern uint32_t SystemCoreClock;
volatile uint16_t ADC_array[ADC_BUFFER_LENGTH * 4];


extern "C" {
#include "interrupts.h"
}

Config config{&fpga.configSaver};				// Construct config handler with list of configSavers

int main(void)
{
	SystemInit();								// Activates floating point coprocessor and resets clock
	InitHardware();

	if (fpga.calibBtn.pin.IsLow()) {			// If calibration button is pressed on startup clear config
		while (fpga.calibBtn.pin.IsLow()) {};	// Wait until button released so as not to activate calibration after release
		config.EraseConfig();
	}

	fpga.ProgramBitstream();

	config.RestoreConfig();
	InitADC();
	InitSPITimer();

	while (1) {

	}
}

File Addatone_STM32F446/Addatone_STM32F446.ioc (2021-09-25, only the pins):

Mcu.UserName=STM32F446ZETx
PA10.GPIO_Label=USB_ID
PA10.Signal=USB_OTG_FS_ID
PA11.GPIO_Label=USB_DM
PA11.Signal=USB_OTG_FS_DM
PA12.GPIO_Label=USB_DP
PA12.Signal=USB_OTG_FS_DP
PA13.GPIO_Label=TMS
PA13.Signal=SYS_JTMS-SWDIO
PA14.GPIO_Label=TCK
PA14.Signal=SYS_JTCK-SWCLK
PA8.GPIO_Label=USB_SOF [TP1]
PA8.Signal=USB_OTG_FS_SOF
PA9.GPIO_Label=USB_VBUS
PA9.Signal=USB_OTG_FS_VBUS
PB0.GPIO_Label=LD1 [Green]
PB0.Signal=GPIO_Output
PB10.Signal=I2S2_CK
PB12.Signal=I2S2_WS
PB14.GPIO_Label=LD3 [Red]
PB14.Signal=GPIO_Output
PB7.GPIO_Label=LD2 [Blue]
PB7.Signal=GPIO_Output
PC1.Signal=I2S2_SD
PC13.GPIO_Label=USER_Btn [B1]
PC13.Signal=GPXTI13
PC14-OSC32_IN.Signal=RCC_OSC32_IN
PC15-OSC32_OUT.Signal=RCC_OSC32_OUT
PC9.Signal=RCC_MCO_2
PD8.GPIO_Label=STLK_RX [STM32F103CBT6_PA3]
PD8.Signal=USART3_TX
PD9.GPIO_Label=STLK_TX [STM32F103CBT6_PA2]
PD9.Signal=USART3_RX
PG6.GPIO_Label=USB_PowerSwitchOn [STMPS2151STR_EN]
PG6.Signal=GPIO_Output
PG7.GPIO_Label=USB_OverCurrent [STMPS2151STR_FAULT]
PG7.Signal=GPIO_Input
PH0-OSC_IN.GPIO_Label=MCO [STM32F103CBT6_PA8]
PH0-OSC_IN.Signal=RCC_OSC_IN
PH1-OSC_OUT.Signal=RCC_OSC_OUT

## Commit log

2020-02-11 Pseudo saw wave implemented
    [compile.cfg]
2020-02-11 Sample Position Array now referenced directly from harmonic number
2020-02-11 tweaks to resolve timing errors (main loop uses single state machine)
    [ADC_SPI_In.v]
2020-02-13 New STM32L152 and 451 dev board
    Reorganised ARM project to use later CMSIS libraries; Reorganised FPGA project to move verilog files to source folder; started troubleshooting frequency errors when potentiometer input values high
    [STM32L152_Dev_Board-B_Cu.gbr, STM32L152_Dev_Board-B_Mask.gbr, STM32L152_Dev_Board-B_Paste.gbr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]
2020-02-14 Refactored ADC code
2020-02-14 Added further error handling to ADC
    [ADC_SPI_In.v]
2020-02-14 ADC now stable with 2x16bit input values
2020-02-14 Dev Board 1.1 layout finalised and gerbers sent to manufacturing
    [STM32L152_Dev_Board-B_Cu.gbr, STM32L152_Dev_Board-B_Mask.gbr, STM32L152_Dev_Board-B_Paste.gbr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]
2020-02-23 Fixes to sample LUT calculations
    [compile.cfg, library.cfg, projlib.cfg]
2020-02-24 First draft of Sample Position module (not yet integrated in main)
2020-02-24 Moved sample position calculation to separate module to reduce overall sample calculation time
    [compile.cfg]
2020-02-26 Changes to use sample position lookup; tidied up top state machine
    [compile.cfg]
2020-02-26 Added javascript tool to graphically assist with sample positioning to reduce crest factor
2020-02-28 Added ARM I2S implementation to test potentially faulty DAC
2020-02-29 Updated sample position LUT tool to scale and export results for use in FPGA RAM
2020-02-29 Added buld script and optimised sample position lookup
2020-03-01 Refactored sample position module to combine sample position and sine LUT lookup
    [compile.cfg]
2020-03-02 (Yet another) rewrite of ADC module to handle noise better
    [ADC_SPI_In.v, main.cpp]
2020-03-04 Added additional ADC channel for controlling harmonic level from CV
    [AddaTone.sch]
2020-03-05 Added second adder module with some refactoring
    [compile.cfg]
2020-03-06 Added Sample Output module to handle sending stereo outs
    [compile.cfg]
2020-03-11 Frequency Scaling implemented (Issue where FPGA has no output until reset)
    [compile.cfg]
2020-03-13 Added additional ADC Channel with macros for simplified configuration
2020-03-13 Preparing to add comb filter control
2020-03-13 Basic comb filtering implemented
2020-03-17 Transferred ADC MCU to STM32L152; tweaks to comb filtering
    [AddaTone.sch]
2020-03-23 Added early draft of support for ICE40UP5k FPGA
    [Addatone_ICE40_impl_1_vo.sdf, PLL_48MHz.cfg, STM32L152_Dev_Board 1.1.kicad_pcb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]
2020-03-23 Mach X03 codebase transferred though not yet working
    [Addatone_ICE40_impl_1_vo.sdf, SamplePos_RAM.cfg]
2020-03-24 ICE40 implementation partially working; adder rewritten to use hardware multiplier
    [Addatone_ICE40_impl_1_vo.sdf]
2020-03-25 Fixed bug in Adder causing polarity of fundamental to flip
    [Addatone_ICE40_impl_1_vo.sdf]
2020-03-26 Added ADC support for separate even harmonic scaler
2020-03-28 Improved resolution of harmonic scale; Fixed issues with frequency scaling
    [AddaTone.sch]
2020-03-29 Added STM32F446 project to test programming FPGA from microcontroller
2020-03-31 Fixed issue in programmer where clock polarity setting was affecting slave select signal
    Also added preliminary work to compress bitstream by encoding repeated zeros
    [main.cpp]
2020-04-03 Rev 2 of dev board; provisional handling for overflow on output samples
    [AddaTone.sch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]
2020-04-03 Cleaned sample output module and reduced sample register size to 24 bits
2020-04-03 Added provisional mix option to Sample_out module
2020-04-04 Implemented Mix switch
    [AddaTone.sch]
2020-04-07 Tweaks to remove warnings and work around ongoing timing issues
    [DAC_SPI_Out.v]
2020-04-09 Updates to schematic
    [AddaTone.sch]
2020-04-10 Updated schematic for PCM5100 DAC
    [AddaTone MAX5134 DAC.sch, AddaTone.sch]
2020-04-11 Started laying out PCB
    [AddaTone components.kicad_pcb, AddaTone components.sch, addatone.kicad_pcb]
2020-04-14 Initial PCB Wiring Completed
    [AddaTone components.kicad_pcb, AddaTone components.sch]
2020-04-15 Updated microcontroller code for correct ADC channels and implemented HSE oscillator output
    [AddaTone components.sch]
2020-04-16 Minor tweaks to PCB layout
    [AddaTone components.sch]
2020-04-16 Rough layout of controls PCB
    [AddaTone Controls.kicad_pcb, AddaTone Controls.sch, AddaTone MAX5134 DAC.sch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]
2020-04-17 Further refinements to PCB layout
    [AddaTone components.sch]
2020-04-18 Refinements to PCB
    [AddaTone Controls.kicad_pcb, AddaTone Controls.sch, AddaTone components.kicad_pcb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]
2020-04-19 First draft of Panel PCB
    [AddaTone Controls.kicad_pcb, Addatone Panel.kicad_pcb]
2020-04-21 Further updates to PCBs
    [AddaTone Controls.kicad_pcb, Addatone Panel.kicad_pcb]
2020-04-21 Checking FPGA programming code and updated bitstream
    [Addatone Panel.kicad_pcb]
2020-04-21 Updated FPGA programming code to use correct pin for Reset; Minor PCB corrections
    [AddaTone Controls.kicad_pcb, AddaTone Controls.sch, AddaTone components.kicad_pcb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]
2020-04-23 I2S Tests updated to work on STM32F446; started added IP based multiplier for Ring Mod
    [AddaTone components.sch, Ring_Mod_Mult.cfg]
2020-04-29 Switched FPGA output to I2S DAC
    [AddaTone components.kicad_pcb, AddaTone components.sch]
2020-05-15 Updates to PCB layout
    [AddaTone Controls-B_Cu.gbr, AddaTone Controls-B_Mask.gbr, AddaTone Controls-B_Paste.gbr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]
2020-06-01 Fixes to schematic (missing resistor on 1.2V LDO); Created new implementation to support production board; added FPGA tester project
    [AddaTone Solder Stencil-B_Cu.gbr, AddaTone Solder Stencil-B_Mask.gbr, AddaTone Solder Stencil-B_Paste.gbr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]
2020-06-02 Updated MCU Code to handle fine tune and octave controls
    [ADC Pins.xlsx]
2020-06-03 Implemented support for harmonic and warp potentiometers
    [main.cpp]
2020-06-03 Updated FPGA constraints to use correct I2S pin names
2021-09-21 Switch octave and fine tune controls
2021-09-21 Updated the code to use the warp CV input to control the number of harmonics
    [fpgaHandler.cpp, fpgaHandler.h, initialisation.cpp]
2021-09-22 Updated panel; altered controls to use CV to adjust harmonic count
    RTL altered to half level of last harmonic to smooth harmonic count CV control
    [Addatone Panel.kicad_pcb, Addatone_ICE40_impl_1_vo.sdf]
2021-09-23 Clean up panel pcb
    [Addatone Panel-B_Cu.gbr, Addatone Panel-B_Mask.gbr, Addatone Panel-B_Paste.gbr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]
2021-09-23 Revised panel gerbers ready for manufacture
    [Addatone Panel-B_Cu.gbr, Addatone Panel-B_Mask.gbr, Addatone Panel-B_Silkscreen.gbr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]
2022-03-11 Updated pcb files to Kicad 6.0
    [AddaTone Controls.kicad_pcb, AddaTone components.kicad_pcb]
2024-01-15 Updating component schematic and PCB to Kicad 7.09
    [AddaTone components.kicad_pcb, AddaTone components.kicad_sch]
2024-01-16 Updated schematic and pcb to v2.1
    [AddaTone components.kicad_pcb, AddaTone components.kicad_sch]
2024-08-25 Updated firmware to support calibration
